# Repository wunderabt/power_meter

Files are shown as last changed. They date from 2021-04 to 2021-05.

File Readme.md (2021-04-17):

# Packet Radio for Power Meter

idea: use 433MHz or 866MHz band to remotely read the power meter

Transceiver: [RFM69](https://www.mikrocontroller.net/articles/RFM69)

attach a sender to the power meter

Power Meter read-out via IR: https://wiki.volkszaehler.org/hardware/controllers/ir-schreib-lesekopf-ttl-ausgang

Sender:
- [Moteino](https://lowpowerlab.com/guide/moteino/)
- [Adafruit Feather](https://learn.adafruit.com/adafruit-feather-32u4-radio-with-rfm69hcw-module)

Receiver:
- [Arduino with Ethernet-Shield and SD-Card Logger](https://store.arduino.cc/arduino-ethernet-shield-2)

The reciver logs all incoming packages and makes them available for queries via network over ethernet.

Shops:
- https://www.distrelec.de (adafruit)
- https://www.makershop.de (adafruit)
- https://www.berrybase.de

Protocol information:
- OBIS codes https://www.promotic.eu/en/pmdoc/Subsystems/Comm/PmDrivers/IEC62056_OBIS.htm
- SML structure example http://www.stefan-weigert.de/php_loader/sml.php

## Structure

```
Power Meter      Adafruit Feather 32u4   866MHz   Arduino Uno       Banana-Pi
ISKRA MT631  --> IR Read Head           --------> Ethernet     -->  InfluxDB
                 RFM69                            RFM69             Grafana
                                                  SD-Card
```

## Sender

The sender wakes up from deep sleep every hour, awaits an SML (**S**mart **M**essage **L**anguage) telegram from the power meter (which sends one every second through the infrared interface) and stores timestamp and power reading in RAM, returns to sleep. When no more entries can be held in RAM it powers up the RFM69 radio and sends all stored readings.

According to the datasheet the adafruit feather consumes 300uA in deep sleep so that in theory a 500mAh battery is sufficient for 500mAh/300uA = 1666.7h = 69.4 days of operation. With the high power phase every hour it will hopefully still last over a month per charge.

### SML fields

We are interested in two fields from an SML telegram (see the full dump in `raw-data/serial-dump-annotate.hex` in this repository)

(1) Timestamp (i.e. uptime)
```
[..]
        63 7 1                                   # getListResponse
        77                                       # List, 7 entries
            1                                    # clientId, no value
            B XX XX XX XX XX XX XX XX XX XX      # serverId
            7 1 0 62 A FF FF                     # OBIS manufacturer
            72                                   # List, 2 entries
                62 1                             # choice: secIndex
                65 0 11 9C 33                    # secIndex (uptime)
[..]
        63 7 1                                   # getListResponse
        77                                       #
            1                                    #
            B XX XX XX XX XX XX XX XX XX XX      # serverId
            7 1 0 62 A FF FF                     # OBIS manufacturer
            72
                62 1                        
                65 0 11 9C 34                    # uptime
```

The uptime is `0x00119C33 = 1154099 sec = 13d8h` and `0x00119C34 = 1154100 sec` respectively. As sanity check: the telegram was received on 2021/04/01 at around 19:00 and the power meter was installed on 2021/03/19 at around 11:00. That matches 13 days and 8 hours.

(2) Power Reading
```
                77                               # List, 7 entries
                    7 1 0 1 8 0 FF               # OBIS 1.8.0*255
                    65 0 10 1 4                  # status ?
                    1                            # valTime
                    62 1E                        # unit: 1e = "Wh"
                    52 3                         # scaler, 3 = k
                    62 2E                        # value: 0x2e = 46 kWh
                    1                            # valueSignature
```

Field lengths can vary. The current `62 2E = 46kWh` will become longer and the 2nd nibble indicates the field length, for example a future reading could be `64 1 2 3 = 291kwH`.

To simplify the code on the sender it will not implement a full SML parser that takes varying field length into account. It will be rather dumb: it checks for the occurence of the interesting OBIS code in the byte stream and then store sufficiently many bytes after that to capture the values. The extraction of the values from that SML snippet is done in postprocessing on the receiver.

### SML snippet storage

#### Timestamp

The timestamp is identified by the byte sequence

    7 1 0 62 A FF FF

and the following 12 bytes are stored although 8 byte are sufficient at the moment but we want to allow a growing time stamp field.

Example
```
        63 7 1
        77
            1
            B XX XX XX XX XX XX XX XX XX XX
            7 1 0 62 A FF FF               <== Marker
            72                             <== start to store
                62 1                        
                65 0 11 9C 34              <== 8th byte
            74
                77
                    7 1 0 60 32 1 1              # OBIS
                    1
                    1
                    1
                    1
                    4 49 53 4B                   # 49 53 48 = "ISK"
                    1
```

#### Power

The power reading is identified by the byte sequence

    7 1 0 1 8 0 FF

and the following 20 bytes are stored although 12 bytes are sufficient at the moment but we want to allow a growing power field.

Example:
```
                77
                    7 1 0 1 8 0 FF         <== Marker
                    65 0 10 1 4            <== start to store 
                    1
                    62 1E
                    52 3
                    62 2E                  <== 12th byte
                    1
                77
                    7 1 0 2 8 0 FF               # OBIS 2.8.0*255
                    1
                    1
                    62 1E                        # "Wh"
                    52 3                         # "k"
                    62 0
                    1
```

### RAM

The following information is stored each hour:

- timestamp: 12 bytes
- power reading: 20 bytes
- battery level of the sender: 2 bytes (int)

A total of 34 bytes - after 24h this amounts to 816 bytes which fits into the 2KB memory.

## Receiver

The receiver is an Arduino with RFM69, Ethernet and SD-Card. It loops over events from Ethernet and the radio. When it receives new data via radio from the sender, which should be 816 bytes every 24h, it appends it to data on the SD-Card. The content of the SD-Card can be accessed through the udp protocol over the ethernet shield.

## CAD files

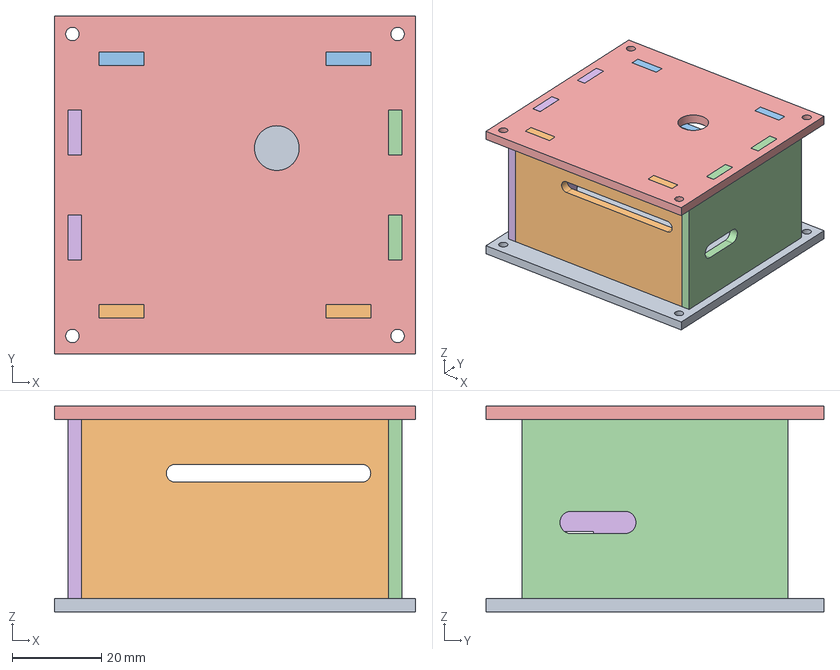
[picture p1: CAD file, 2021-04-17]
freecad/gateway_case.FCStd
80.7 x 75.5 x 46.0 mm
bottom
sideR
sideL
back
top
front

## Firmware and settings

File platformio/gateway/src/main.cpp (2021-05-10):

/*
  Power Meter Gateway

  receives data packets through an RFM69 and stores them on SD-Card
  stored data is served through http via ethernet shield

  by Uwe Brandt

  SPI chip selects:
  10 - ethernet
   4 - SD Card
   5 - RFM69
 */

#include <SPI.h>
#include <Ethernet.h>
#include <EthernetUdp.h>
#include <SD.h>
#include <RH_RF69.h>
#include <RHReliableDatagram.h>

// Enter a MAC address and IP address for your controller below.
// The IP address will be dependent on your local network:
byte mac[] = {
  0xDE, 0xAD, 0xBE, 0xEF, 0xFE, 0xED
};
IPAddress ip(192, 168, 178, 177);
const unsigned int localPort = 8888;      // local port to listen on
EthernetUDP Udp;

const uint8_t sdcard_cs_pin   =  4;
const uint8_t rfm69_cs_pin    =  5;
const uint8_t rfm69_int_pin   =  3;
const uint8_t rfm69_rst_pin   =  2;
const uint8_t ethernet_cs_pin = 10;

#define RF69_FREQ         999.9
#define RF69_ADDRESS        1
#define SD_FILENAME "readings.hex"

uint8_t rf69_key[] = { 0x01, 0x01, 0x01, 0x01, 0x01, 0x01, 0x01, 0x01,
                       0x01, 0x01, 0x01, 0x01, 0x01, 0x01, 0x01, 0x01};

// Singleton instance of the radio driver
RH_RF69 rf69(rfm69_cs_pin, rfm69_int_pin);

// Class to manage message delivery and receipt, using the driver declared above
RHReliableDatagram rf69_manager(rf69, RF69_ADDRESS);
uint8_t msg_buf[RH_RF69_MAX_MESSAGE_LEN];

void spi_select(uint8_t pin) {
  if (pin == sdcard_cs_pin) {
    digitalWrite(ethernet_cs_pin, HIGH);
    digitalWrite(rfm69_cs_pin,    HIGH);
  } else if (pin == ethernet_cs_pin) {
    digitalWrite(sdcard_cs_pin,   HIGH);
    digitalWrite(rfm69_cs_pin,    HIGH);
  } else {
    digitalWrite(ethernet_cs_pin, HIGH);
    digitalWrite(sdcard_cs_pin,   HIGH);
  }
  digitalWrite(pin, LOW); // LOW = active
}

void setup() {
  // Open serial communications and wait for port to open:
  Serial.begin(9600);
  while (!Serial) {
    ; // wait for serial port to connect. Needed for native USB port only
  }

  // SD-Card Setup
  pinMode(sdcard_cs_pin, OUTPUT);

  // RFM69 Setup
  pinMode(rfm69_cs_pin, OUTPUT);
  spi_select(rfm69_cs_pin);
  pinMode(rfm69_rst_pin, OUTPUT);
  digitalWrite(rfm69_rst_pin, LOW);
  digitalWrite(rfm69_rst_pin, HIGH); // manual reset
  delay(10);
  digitalWrite(rfm69_rst_pin, LOW);
  delay(10);

  if (!rf69_manager.init()) {
    // Serial.println("RFM69 radio init failed");
    while (1);
  }
  rf69.setFrequency(RF69_FREQ);
  //Serial.println("RFM69 radio init OK!");
  /* if (!rf69.setFrequency(RF69_FREQ)) {
    Serial.println("setFrequency failed");
  } */
  // If you are using a high power RF69 eg RFM69HW, you *must* set a Tx power with the
  // ishighpowermodule flag set like this:
  rf69.setTxPower(20, true);  // range from 14-20 for power, 2nd arg must be true for 69HCW

  // The encryption key has to be the same as the one in the server
  rf69.setEncryptionKey(rf69_key);
  //Serial.print("RFM69 radio @");  Serial.print((int)RF69_FREQ);  Serial.println(" MHz");

  // Ethernet Setup
  pinMode(ethernet_cs_pin, OUTPUT);
  spi_select(ethernet_cs_pin);
  Ethernet.begin(mac, ip);

  // Check for Ethernet hardware present
  if (Ethernet.hardwareStatus() == EthernetNoHardware) {
    //Serial.println("Ethernet shield was not found.  Sorry, can't run without hardware. :(");
    while (true) {
      delay(1); // do nothing, no point running without Ethernet hardware
    }
  }
  Udp.begin(localPort);
  Serial.println("ready");
}

void send_udp_message(char* msg) {
  spi_select(ethernet_cs_pin);
  Udp.beginPacket(Udp.remoteIP(), Udp.remotePort());
  Udp.write((char *)msg);
  Udp.endPacket();
} 

void loop() {
  // listen for incoming clients
  spi_select(ethernet_cs_pin);
  int packetSize = Udp.parsePacket();
  if (packetSize) {
    spi_select(sdcard_cs_pin);
    if (SD.begin(sdcard_cs_pin)) {
      File dataFile = SD.open(SD_FILENAME, FILE_READ);
      msg_buf[RH_RF69_MAX_MESSAGE_LEN-1] = '\0';
      if (dataFile) {
        while (dataFile.available()) {
          dataFile.read(&msg_buf, RH_RF69_MAX_MESSAGE_LEN-1);
          send_udp_message((char *)msg_buf);
          spi_select(sdcard_cs_pin);
        }
        dataFile.close();
      }
    }
    // send a UDP package with a "END" sequence
    char eot[] = "\n\nEOT";
    send_udp_message(eot);
  }

  spi_select(rfm69_cs_pin);
  if (rf69_manager.available())
  {
    // Wait for a message addressed to us from the client
    uint8_t len = sizeof(msg_buf);
    uint8_t from;
    if (rf69_manager.recvfromAck(msg_buf, &len, &from)) {
      Serial.println(len);
      spi_select(sdcard_cs_pin);
      if (SD.begin(sdcard_cs_pin)) {
          File dataFile = SD.open(SD_FILENAME, FILE_WRITE);
          if (dataFile) {
            for (uint8_t i = 0; i < len; i++) {
              dataFile.print(msg_buf[i], HEX); dataFile.print(" ");
            }
            dataFile.println();
            dataFile.close();
          } // else {
            // Serial.println("Can't write file");
          // }
      } // else {
        //Serial.println("poop");
      // }
      spi_select(rfm69_cs_pin);
      uint8_t ack[] = { 0xAA };
      rf69_manager.sendtoWait(ack, 1, from);
    }
  }
}

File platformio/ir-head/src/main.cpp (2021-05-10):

#include <SPI.h>
#include <RH_RF69.h>
#include <RHReliableDatagram.h>
#include <Adafruit_SleepyDog.h>

// #define DEBUG 1 // comment in for USB debug
// CONSTANTS
#define RFM69_DEST_ADDRESS   1
// change addresses for each client board, any number :)
#define RFM69_ADDRESS        2
#define RFM69_FREQ         999.9

#define RFM69_CS      8
#define RFM69_INT     7
#define RFM69_RST     4
#define LED           13

#define VBATPIN    A9
#define IRPOWERPIN A5
const byte SML_START_SEQUENCE[] = {0x1B, 0x1B, 0x1B, 0x1B, 0x01, 0x01, 0x01, 0x01};
const byte SML_OBIS_TIMESTAMP[] = {0x07, 0x01, 0x00, 0x62, 0x0A, 0xFF, 0xFF};
const byte SML_OBIS_POWER[]     = {0x07, 0x01, 0x00, 0x01, 0x08, 0x00, 0xFF};

const int num_timestamp_bytes  =   12;
const int num_power_bytes      =   20;
const int num_memory_entries   =   24; // entries for one day, one entry each hour
const uint16_t sample_interval = 3600; // 3600s = 1h

uint8_t rf69_key[] = { 0x01, 0x01, 0x01, 0x01, 0x01, 0x01, 0x01, 0x01,
                       0x01, 0x01, 0x01, 0x01, 0x01, 0x01, 0x01, 0x01};
const uint8_t rf69_retries = 20;
const int     rf69_retry_pause = 2000; // 2s

// GLOBALS
// Singleton instance of the radio driver
RH_RF69 rf69(RFM69_CS, RFM69_INT);

// Class to manage message delivery and receipt, using the driver declared above
RHReliableDatagram rf69_manager(rf69, RFM69_ADDRESS);

uint8_t rf69_buf[RH_RF69_MAX_MESSAGE_LEN];

struct PowerReading {
  byte timestamp[num_timestamp_bytes];
  byte power[num_power_bytes];
  int bat_volt;
} readings[num_memory_entries];
int cur_reading_idx = 0;



void setup() {
  // USB debug port
  Serial.begin(9600);
#ifdef DEBUG  
  while (!Serial) {
    ; // wait for serial port to connect. Needed for native USB port only
  }
#endif
  // IR Header from power meter
  pinMode(IRPOWERPIN, OUTPUT);
  digitalWrite(IRPOWERPIN, LOW);
  Serial1.begin(9600);
  Serial1.setTimeout(1500); // a bit more than 1 sec because the powermeter only sends every 1 sec

  // RFM69 init
  pinMode(RFM69_RST, OUTPUT);
  digitalWrite(RFM69_RST, LOW);

  // manual reset
  digitalWrite(RFM69_RST, HIGH);
  delay(10);
  digitalWrite(RFM69_RST, LOW);
  delay(10);

  if (!rf69_manager.init()) {
    Serial.println("RFM69 radio init failed");
    while (1);
  }
  Serial.println("RFM69 radio init OK!");
  // Defaults after init are 434.0MHz, modulation GFSK_Rb250Fd250, +13dbM (for low power module)
  // No encryption
  if (!rf69.setFrequency(RFM69_FREQ)) {
    Serial.println("setFrequency failed");
  }

  // If you are using a high power RF69 eg RFM69HW, you *must* set a Tx power with the
  // ishighpowermodule flag set like this:
  rf69.setTxPower(20, true);  // range from 14-20 for power, 2nd arg must be true for 69HCW

  rf69.setEncryptionKey(rf69_key);

#ifdef DEBUG  
  Serial.print("RFM69 radio @");  Serial.print((int)RFM69_FREQ);  Serial.println(" MHz");

  // send a message that we restarted
  uint8_t start_msg[] = "restart";
  if (rf69_manager.sendtoWait(start_msg, sizeof(start_msg), RFM69_DEST_ADDRESS)) {
    // Now wait for a reply from the server
    uint8_t len = sizeof(rf69_buf);
    uint8_t from;
    if (rf69_manager.recvfromAckTimeout(rf69_buf, &len, 2000, &from)) {
      Serial.print("Got reply from #"); Serial.print(from);
      Serial.print(" [RSSI :");
      Serial.print(rf69.lastRssi());
      Serial.print("] : ");
    } else {
      Serial.print("got no reply");
    }
  } else {
    Serial.print("send restart message failed");
  }
#endif
  // RFM96 starts powered off
  rf69.sleep();

  // pause for 20s before we go into deep sleep where USB turns off
  // (this allows us to press reset and have time to initiate upload of new firmware)
  delay(20000);
}

void long_sleep(uint16_t secs) {
  // according to https://forums.adafruit.com/viewtopic.php?f=8&p=721794#p721573
  // the max sleep time for 32u4 via watchdog is 8 sec
  int loop_count = secs / 8;
  for (int i=0; i<loop_count; i++) {
    Watchdog.sleep(8000);
  }
  Watchdog.sleep((secs % 8)*1000);
}


bool find_sequence(const byte *seq, size_t len) {
  // it appears as if Stream.find(..) doesn't work with 0x00 bytes (?)
  // so I wrote this naive matcher
  size_t pos = 0;
  int count = 0;
  while (1) {
    if (Serial1.available()) {
      byte inByte = Serial1.read();
      if (pos > 0 && inByte != seq[pos]) {
        pos = 0;
      } else if (inByte == seq[pos]) {
        pos++;
      }
      if (pos == len) {
        return true;
      }
      count++;
      if (count > 999) {
        return false; // abort search
      }
    }
  }
}

// returns true when send was successful
bool send_data(byte *data, int data_len) {
  if (rf69_manager.sendtoWait(data, data_len, RFM69_DEST_ADDRESS)) {
    // Now wait for a reply from the server
    uint8_t len = sizeof(rf69_buf);
    uint8_t from;
    if (!rf69_manager.recvfromAckTimeout(rf69_buf, &len, 2000, &from)) {
      return false;
    }
  } else {
    return false;
  }
  return true;
}


void loop() {
  // read timestamp and power from IR and store in RAM
  digitalWrite(IRPOWERPIN, HIGH); // power up the IR head
  delay(100);
  if (find_sequence(SML_START_SEQUENCE, sizeof(SML_START_SEQUENCE))) {
    if (find_sequence(SML_OBIS_TIMESTAMP, sizeof(SML_OBIS_TIMESTAMP))) {
      Serial1.readBytes(readings[cur_reading_idx].timestamp, num_timestamp_bytes);
      if (find_sequence(SML_OBIS_POWER, sizeof(SML_OBIS_POWER))) {
        Serial1.readBytes(readings[cur_reading_idx].power, num_power_bytes);
        readings[cur_reading_idx].bat_volt = analogRead(VBATPIN);
        cur_reading_idx++;
      } else { Serial.println("no SML power sequence found"); }
    } else { Serial.println("no SML timestamp sequence found"); }
  } else { Serial.println("no SML start sequence found"); }
  digitalWrite(IRPOWERPIN, LOW); // power down the IR head

#ifdef DEBUG
  // debug print
  Serial.print("TIMESTAMP: ");
  for (int i = 0; i < num_timestamp_bytes; i++) {
    Serial.print(readings[cur_reading_idx-1].timestamp[i], HEX); Serial.print(" ");
  }
  Serial.println();
  Serial.print("POWER: ");
  for (int i = 0; i < num_power_bytes; i++) {
    Serial.print(readings[cur_reading_idx-1].power[i], HEX); Serial.print(" ");
  }
  Serial.println();
#endif


  if (cur_reading_idx == num_memory_entries) {
    // RAM full
    // Send a message to the DESTINATION!
    for (int i=0; i<num_memory_entries; i++) {
      uint8_t retries = 0;
      while (retries < rf69_retries) {
        retries++;
        bool send_success = send_data(readings[i].timestamp, num_timestamp_bytes) && \
                            send_data(readings[i].power, num_power_bytes) && \
                            send_data((uint8_t*)&readings[i].bat_volt, 2);
        if (send_success) {
          break;
        }
        delay(rf69_retry_pause);
      }
    }
    cur_reading_idx = 0;
    rf69.sleep();
  }
#ifdef DEBUG
  delay(2000);
#else
  long_sleep(sample_interval);
#endif
}

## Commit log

2021-04-17 sanitized version
    [gateway_case.FCStd]
2021-05-02 switch from Arduino IDE to PlatformIO
